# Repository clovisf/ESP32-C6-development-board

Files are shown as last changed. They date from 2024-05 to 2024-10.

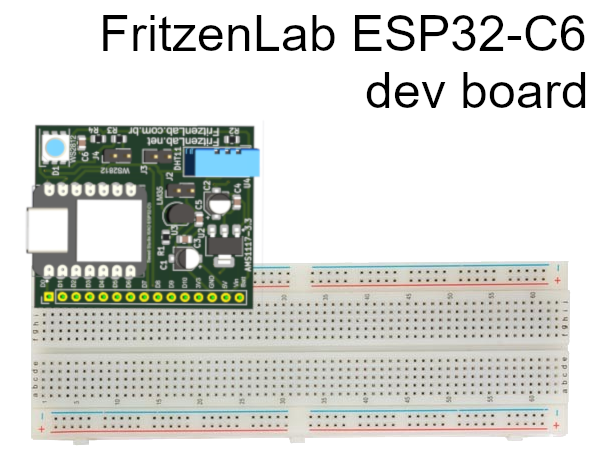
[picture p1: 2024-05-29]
Images/breadboard-connection-esp32-c6.png

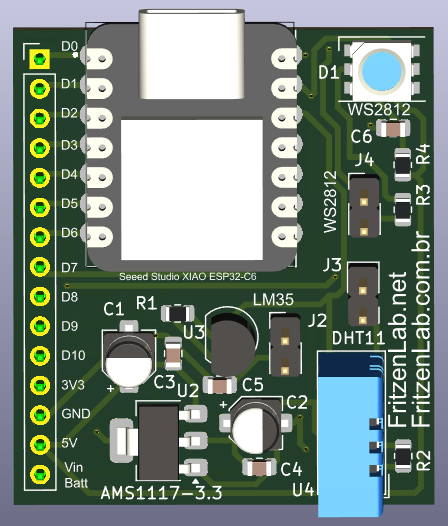
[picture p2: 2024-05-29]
Images/esp32-c6-dev-board-raw.png

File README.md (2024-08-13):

A development board for the new WiFi ESP32-C6 chip from SeeedStudio (Xiao line), featuring a DHT11 temperature sensor, a LDR light sensor and a WS2812b RGB LED. It can be mounted to a breadboard on a single line, taking up less space.
More info at: https://fritzenlab.com.br/fritzenlab-esp32-c6-dev-board/ or https://fritzenlab.net/fritzenlab-esp32-c6-dev-board/

esp32-c6-fritzenlab-pinout-1024x724 (1)

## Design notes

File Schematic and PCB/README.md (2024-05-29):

esp32-c6-versao-final

This is a development board based around the ESP32-C6 WiFi chip, model Xiao from SeeedStudio. All productions files are made in Kicad. The board features a 15-pin single row to be connected directly to a breadboard.
It has slots for a LM35 temperature sensor, a DHT11 temperature and humidity sensor and a WS2812 neopixel addressable RGB LED. It also contains a 3.3V LM1117 voltage regulator to power the chip when offering 5V on the board pins.
More details at: https://fritzenlab.com.br or https://fritzenlab.net

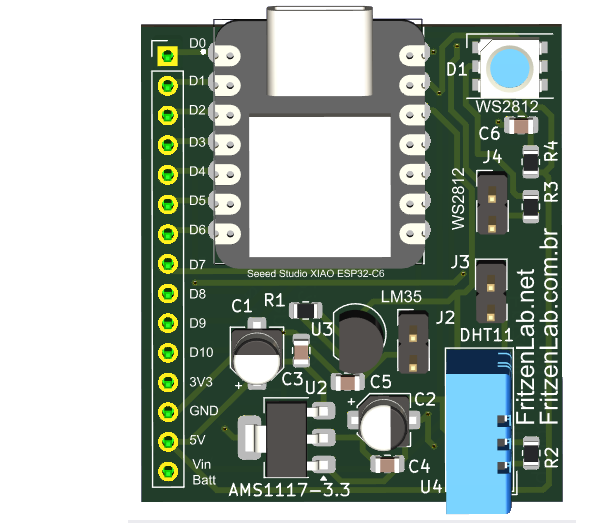
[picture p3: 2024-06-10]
Images/Pinout-esp32-c6-dev-board-fritzenlab.png

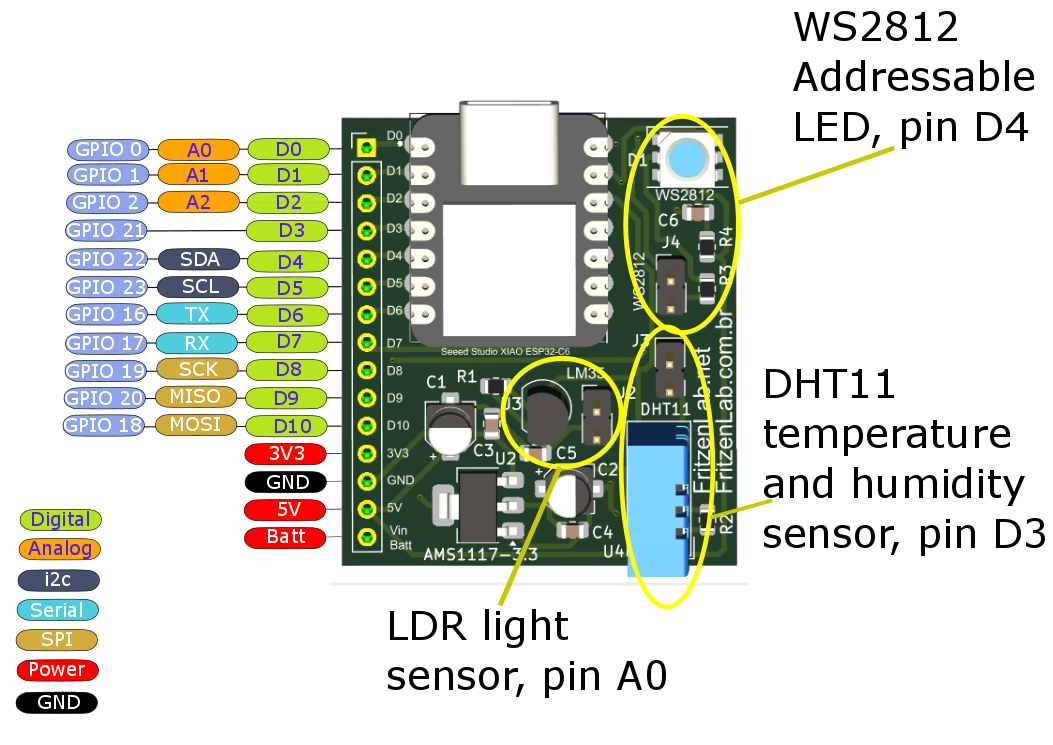
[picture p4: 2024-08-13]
Images/esp32-c6-fritzenlab-pinout.png

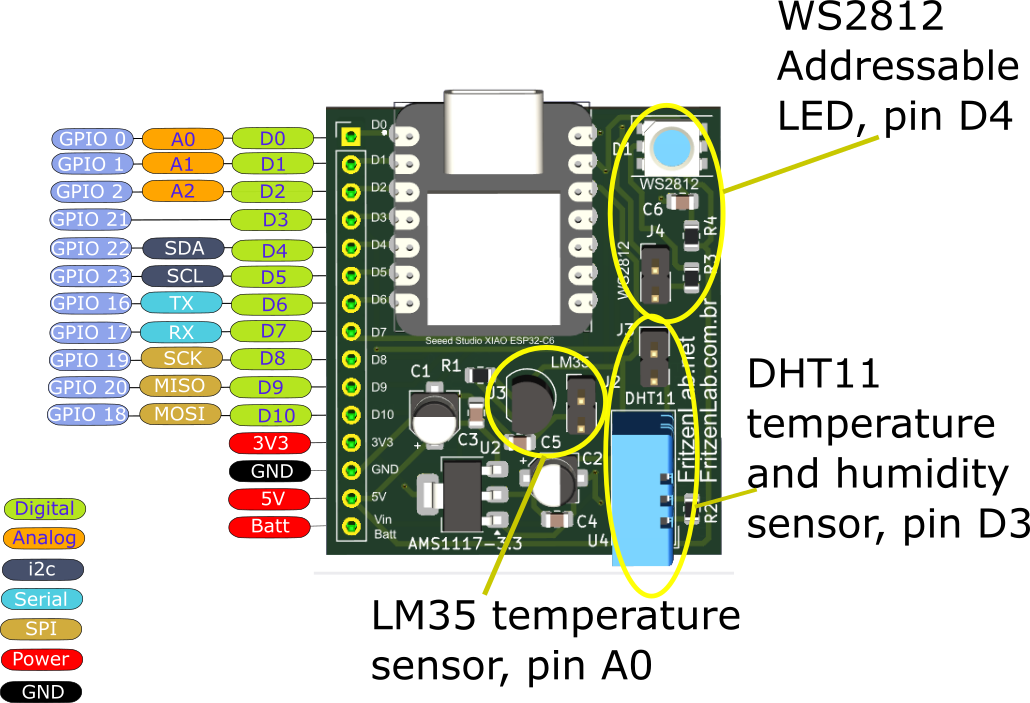
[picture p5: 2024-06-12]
esp32-c6-pinout.png

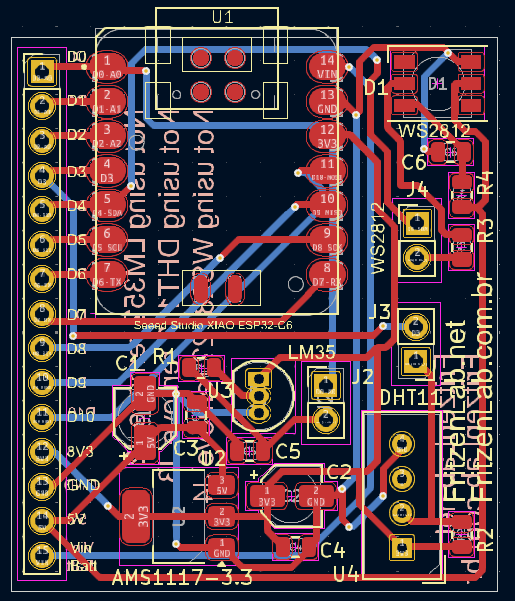
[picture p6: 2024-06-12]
Images/esp32-c6-layout.png

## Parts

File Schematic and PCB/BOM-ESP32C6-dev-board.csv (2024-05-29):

Id | Designador | Footprint | Quantidade | Designação | Fornecedor e referência
3 | C1,C2 | CP_Elec_4x5.4 | 12 | 10u | https://www.ryndackcomponentes.com.br/capacitor-eletrolitico-smd-10-f-25v-105-c-10uf.html
2 | C3,C6,C5,C4 | C_0805_2012Metric | 25 | 100n | https://www.ryndackcomponentes.com.br/capacitor-ceramico-100nf-50v-smd-0805.html
13 | D1 | LED_WS2812_PLCC6_5.0x5.0mm_P1.6mm | 7 | WS2812 | https://www.ryndackcomponentes.com.br/ws2812-led-rgb-enderecavel-smd-5050-6-pinos.html
10 | J1 | PinHeader_1x15_P2.54mm_Vertical | 4 | Conn_01x15_Pin | https://www.ryndackcomponentes.com.br/barra-de-pinos-1x40-14-5mm-passo-2-54mm-90.html
10 | J1 | PinHeader_1x15_P2.54mm_Horizontal | 4 | Conn_01x15_Pin | https://www.ryndackcomponentes.com.br/barra-de-pinos-1x40-11-2mm-passo-2-54mm-180.html
1 | J2,J4,J3 | Jumper 2.54 | 20 | Conn_01x02_Pin | https://www.ryndackcomponentes.com.br/jumper-com-aba-preto-2-54mm.html
8 | R1, R3 | R_0805_2012Metric | 2 | 470 | Tenho em estoque
6 | R2 | R_0805_2012Metric | 1 | 10k | Tenho em estoque
4 | R4 | R_0805_2012Metric | 1 | R | Tenho em estoque
5 | U1 | Seeeduino XIAO-MOUDLE14P-2.54-21X17.8MM | 1 | Seeed Studio XIAO ESP32-C6 | Tenho em estoque
12 | U2 | SOT-223-3_TabPin2 | 7 | AMS1117-3.3 | https://www.ryndackcomponentes.com.br/ams1117-3-3-regulador-de-tens-o-3-3v-3v3-1a-sot223-lm1117-3-3.html
9 | U3 | TO-92_Inline | 7 | LM35 | https://www.ryndackcomponentes.com.br/lm35dz-sensor-de-temperatura-analogico.html
7 | U4 | Aosong_DHT11_5.5x12.0_P2.54mm | 1 | DHT11 | Tenho em estoque

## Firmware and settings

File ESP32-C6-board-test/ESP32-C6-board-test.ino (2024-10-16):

#include "DHT.h"

#define DHTPIN D3     // Digital pin connected to the DHT sensor
// Feather HUZZAH ESP8266 note: use pins 3, 4, 5, 12, 13 or 14 --
// Pin 15 can work but DHT must be disconnected during program upload.

// Uncomment whatever type you're using!
#define DHTTYPE DHT11   // DHT 11
//define DHTTYPE DHT22   // DHT 22  (AM2302), AM2321
//#define DHTTYPE DHT21   // DHT 21 (AM2301)


DHT dht(DHTPIN, DHTTYPE);

#include <Adafruit_NeoPixel.h>      //Adiciona a biblioteca Adafruit NeoPixel
#define D_in D4       //Nomeia o pino 6 do Arduino
#define qtdeLeds 1    //Informa a quantidade de LEDs que serão ligados em cascata
Adafruit_NeoPixel pixels(qtdeLeds, D_in);     //Instancia o objeto "pixels", informando a quantidade e o pino de sinal

void setup() {
  // put your setup code here, to run once:
  pinMode(D_in, OUTPUT); 
  Serial.begin(9600);
  dht.begin();
  pixels.begin();

}

void loop() {
  // put your main code here, to run repeatedly:

  // Reading temperature or humidity takes about 250 milliseconds!
  // Sensor readings may also be up to 2 seconds 'old' (its a very slow sensor)
  float t = dht.readTemperature();
  int ldr= analogRead(A0);

  // Check if any reads failed and exit early (to try again).
  if (isnan(t)) {
    Serial.println(F("Failed to read from DHT sensor!"));
    return;
  }
  Serial.print(F("Temperature: "));
  Serial.print(t);
  Serial.println(F("°C "));
  Serial.print("Nivel de luz= ");
  Serial.println(ldr);

  int mapldrpixels= map(ldr, 0, 4095, 0, 254);
  //pixels.clear();      //desliga todos os LEDs
  pixels.setPixelColor(0, pixels.Color(255, 0, 0));     //liga o led correspondente ao número da variável i na cor vermelha
  pixels.show();
  delay(1000);
  pixels.setPixelColor(0, pixels.Color(0, 255, 0));     //liga o led correspondente ao número da variável i na cor vermelha
  pixels.show();
  delay(1000);
  pixels.setPixelColor(0, pixels.Color(0, 0, 255));     //liga o led correspondente ao número da variável i na cor vermelha
  pixels.show();
  delay(1000);
  pixels.clear();

}

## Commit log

2024-05-27 finished routing with 0.5mm traces
    [ESP32C6-dev-board.kicad_sch]
2024-05-27 added dxf board outline
2024-05-28 Added LM35, DHT11 and WS2812
    Added LM35, DHT11 and WS2812
    [ESP32C6-dev-board.kicad_sch]
2024-05-28 Almost finished polising the PCB
    Almost finished polising the PCB, minor details are lacking
    [ESP32C6-dev-board-B_Cu.gbr, ESP32C6-dev-board-B_Mask.gbr, ESP32C6-dev-board-B_Paste.gbr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]
2024-05-28 Finished the PCB editing
    Finished the PCB editing, sent to production at PCBWAY
    [ESP32C6-dev-board-B_Cu.gbr, ESP32C6-dev-board-B_Mask.gbr, ESP32C6-dev-board-B_Paste.gbr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]
2024-05-29 added bill of materials
    added bill of materials with Brazilian stores
    [BOM-ESP32C6-dev-board.csv]
2024-06-07 added schematic diagram image
2024-06-19 folders reorganized
    [BOM-ESP32C6-dev-board.csv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]
2024-10-16 finished modifications for R01
    [ESP32C6-dev-board.kicad_sch]
2024-10-18 Generated Gerbers
    [ESP32C6-dev-board-B_Cu.gbr, ESP32C6-dev-board-B_Mask.gbr, ESP32C6-dev-board-B_Paste.gbr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]
